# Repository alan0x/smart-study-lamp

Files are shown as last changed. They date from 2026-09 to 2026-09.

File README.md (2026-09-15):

# Smart Study Lamp / 学习台灯 V3

一套可用于 3D 打印打样的学习台灯结构模型。底座容纳 Mac mini M4，灯柱内可走线，并带有可拆屏幕支架和绿联 USB 摄像头安装模块。

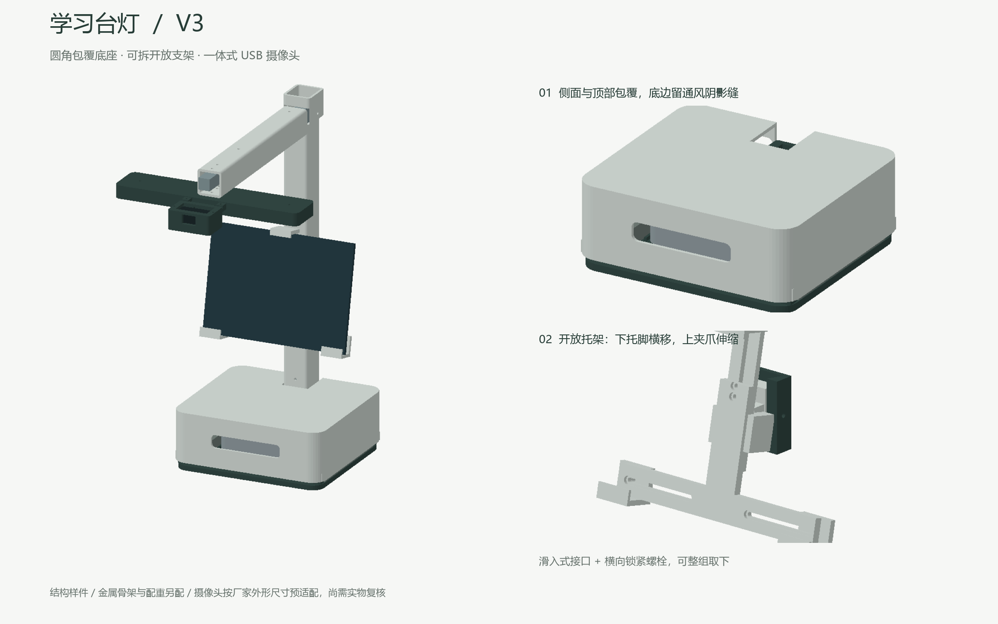
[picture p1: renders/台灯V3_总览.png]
V3 总览


## 当前设计

- 圆角包覆式底座，侧面和顶部遮蔽 Mac mini，底部保留进风空间。
- 20 × 20 × 1.5 mm 钢方管承重骨架；打印件只承担外壳、定位和连接作用。
- 可拆开放式屏幕支架，目标夹持高度 130–220 mm。
- 摄像头安装腔按不含底座的 59 × 35 × 23 mm 机身设计。
- 灯柱与横臂内预留线束通道，并给屏幕、LED 和摄像头设置出线口。
- 灯头预留通用 LED 铝槽容纳空间；灯条、铝槽、扩散罩、调光器和电源尚未选定。

## 查看模型

- `assembly_view_only.glb`：完整装配预览，包含设备和金属骨架占位，不可整体打印。
- `assembly_view_only.3mf`：同一装配的 3MF 版，可直接用 Bambu Studio 打开逐件查看，不可打印。
- `stl/`：18 个独立打印文件，单位均为毫米。
- `renders/`：整灯、爆炸图、分步装配与拆装渲染图。

Windows 可直接尝试打开 GLB；也可使用 Blender。查看和切片 STL 可以使用 [Bambu Studio](https://bambulab.cn/zh-cn/download/studio)。

## 打印前必读

这是结构样件，还未进行实物承重、防倾倒、温升、照度、眩光和摄像头覆盖范围测试。建议先打印 16–18 号配合试片，以及 09/10 号摄像头适配件。

完整尺寸、采购参考和装配顺序见：

- [设计与打印说明](docs/设计与打印说明.md)
- [V3 更新与走线说明](docs/V3更新与走线说明.md)

## 重新生成模型

建模源文件位于 `model/build_lamp_v3.py`。安装依赖后，在仓库根目录运行：

```powershell
python -m pip install -r requirements.txt
python model/build_lamp_v3.py
```

脚本会在 `outputs/V3` 下重新生成 STL、预览图和校验结果。中文标注渲染目前会优先使用 Windows 的微软雅黑字体。

整灯爆炸图由 `model/build_exploded_view.py` 生成，分步装配示意由 `model/build_assembly_steps.py` 生成（均会先完整运行建模脚本），分别输出到 `renders/台灯V3_爆炸图.png` 和 `renders/台灯V3_分步装配.png`。

## 版本状态

V3 已完成数字几何检查：18 个 STL 均为封闭、正体积、单一连通网格；打印件、设备包络和预留线束探针没有检测到体积干涉。数字检查不能替代实物装配和安全测试。

本仓库暂未声明开源许可证；未经许可，不自动授予复制、修改或再发布权利。

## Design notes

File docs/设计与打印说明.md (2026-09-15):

> V3 补充说明优先：摄像头依据客服提供的本体约 59×35×23 mm 建模。视场角未确认，当前高度并未证明能覆盖 600×400 mm 桌面。

# 学习台灯 V3：圆角外罩、开放式可拆支架、USB 摄像头成品适配

## 这次改动

1. Mac mini 与两侧配重收进圆角底座，侧面与顶面包覆，顶部不再有通风栅格或外露紧固件。底边留通风缝，前面留接口窗口，后面留插线窗口。
2. 屏幕改成开放 T 形托架：两只下托脚左右移动，上夹爪上下伸缩。支架通过滑入式连接座安装到灯柱，拔出横向锁紧螺栓、上提约 66 mm 后，可整组取下。灯柱连接座可以保留供以后安装别的模块。
3. 摄像头按 **UGREEN 59×35×23 mm** 金属外壳成品预适配，摄像头与 mic 共用 USB 线，原装金属外壳保留；不用把带显示器夹具的现有摄像头塞进小仓内。

这是经过数字几何检查的 **V3 结构样件**，可以询价、试打。承重、跌落、防倾倒、温升、照度和摄像头实拍尚未验证，不能视为已经定型的整灯。机身尺寸通过不代表按键、底脚、实际线缆和镜头细节已经全部确认。

## 文件内容

- STL 文件夹：**15 个装配件 + 3 个配合试片，共 18 个文件**，每个各 1 件。
- 台灯V3_总览.png：真实模型渲染，包含整灯和局部外观。
- 台灯V3_爆炸图.png：整灯爆炸图，标注打印件编号与另购件位置，由 model/build_exploded_view.py 生成。
- 台灯V3_分步装配.png：六步装配示意，含每步紧固件要点，由 model/build_assembly_steps.py 生成。
- 台灯V3_拆装细节.png：底座、屏幕连接、摄像头安装座的拆解示意。
- assembly_view_only.glb：保留装配坐标的三维查看模型，包含非打印设备与金属骨架占位，不能整体打印。
- mesh_validation.json：网格、干涉和若干运动位置检查结果。
- editable_model.py：可编辑建模源文件，需 Python、numpy、trimesh、manifold3d、matplotlib；运行目录中生成 outputs/V3。图片需系统可用中文字体。
- V3更新与走线说明.md：摄像头尺寸、走线路线与实物复核要求。

STL 单位均为 **mm，按 100% 比例导入**。每件独立摆放，不保留装配位置；部分件已旋转以便切片。不要通过整件缩放来调整局部配合。以 GLB 查看装配关系，以 STL 单件打印。

## 主要尺寸

| 项目 | V3 |
|---|---|
| 底座包络 | 260 × 240 × 98 mm，不计另贴的防滑脚垫 |
| 外壳 | 侧壁约 4 mm、顶板 4 mm、平面转角半径 24 mm |
| 底座通风 | 外罩下沿高 14 mm，内底板上表面高 8 mm，中间留 6 mm 通风阴影缝 |
| Mac 底面 / 顶面 | 名义 Z=30 / 80 mm，罩内顶面 Z=94 mm，顶上约 14 mm 空间 |
| 总高 | 584 mm，不计防滑脚垫 |
| 灯头主体 | 320 × 68 × 22 mm |
| 摄像头名义镜头位置 | 约 X=0、Y=-308、Z=491 mm，实际光心待实物确认 |
| 屏幕设计范围 | 目标设备 iPad Pro 11″（2021，247.6×178.5×5.9 mm，466 g）横放；夹持高度 130–220 mm；结构试配宽度约 140–250 mm；厚度约 6–13 mm 需软垫补偿 |
| 屏幕姿态 | 后倾 12°，V3 没有角度转轴 |
| 下托脚中心 | 左右各可在距中线 35–106 mm 的位置锁紧；iPad Pro 11 横放建议各 106 mm，使底边完全承托 |

这里的“夹持高度”指上下接触边之间的距离，不是屏幕对角线。按设备实际长宽和摆放方向判断是否适用，例如较大的平板可能需要横放。宽度只是结构适配目标，没有经过所有设备试装。台灯整体承载上限尚未通过测试；首轮应从与 iPad Pro 11（466 g）等重量的假负载开始验证，不能据此装大尺寸桌面显示器。

托架没有四边包框，两侧接口通常更易露出，但上夹爪、下托脚仍可能遇到特定机型的按键、USB 接口或磁吸附件。软垫应补偿厚度与保护接触边，不要硬夹显示区域。后部螺栓头采用凹位，必须选择能藏入凹位的低圆头螺栓，避免顶到设备背面。

## 底座：包起来，但保留真实风路

Mac mini M4 的通风经过底脚区域，Apple 官方介绍了这一结构。[Apple 的 M4 Mac mini 发布说明](https://www.apple.com.cn/newsroom/2024/10/apples-all-new-mac-mini-is-even-more-mighty-and-more-mini/)

因此外罩覆盖侧面与上面，电脑下方只保留四个短托点，中央开放；配重位于电脑左右，不放在电脑底部。外罩下沿不贴住内底板，空气从底边和后侧窗口进出。Mac 前后接口用较大的共用窗口让位，未按未经核实的端口坐标逐孔开小孔。

6 mm 通风缝、30 mm 底面高度和14 mm 顶部间隙均是初始设计值，不是热设计结论。包覆后仍需与裸机对比满负载温度、风扇噪声和性能；若出现热积聚，应扩大下缘或后部通风区域。外壳不能贴合封死底脚。底面电源键的手指操作与真实底脚需试装，必要时拆罩操作。

外罩用底面四颗 M3 螺丝固定，顶部无外露螺丝；螺纹由四个 M3 热熔嵌件提供。外罩后面有 U 形灯柱让位缺口，拆外罩不必拆整根灯柱。建议先取下屏幕模块，拔掉电脑外接线，再卸底面螺丝，提罩约 80 mm 后向前移出。拆解图为了显示内部使用了更大的抬升距离，不代表唯一拆卸路径。

## 分件清单

| 编号 | 部件 | 数量 |
|---|---|---:|
| 01 | 隐藏式内底架、电脑托点和方管插座 | 1 |
| 02 | 圆角外罩 | 1 |
| 03 / 04 | 灯柱下 / 上套壳 | 各 1 |
| 05 / 06 | 灯臂后 / 前套壳 | 各 1 |
| 07 | 转角罩 | 1 |
| 08 | 圆角灯头 | 1 |
| 09 / 10 | 绿联成品摄像头承座 / 后压盖 | 各 1 |
| 11 | 固定在灯柱上的滑入连接座 | 1 |
| 12 | 开放屏幕载架，后方一体式插舌 | 1 |
| 13 / 14 | 左 / 右下托脚 | 各 1 |
| 15 | 可滑动上夹爪 | 1 |
| 16 | 20.6 mm 方管孔试片 | 1 |
| 17 / 18 | 滑轨母槽 / 公舌配合试片 | 各 1 |

## 金属、紧固件与电子件

### 承重骨架与配重

初始骨架用 20 × 20 × 1.5 mm 钢方管：立管长 532 mm，横管长 384 mm，由加工方焊成刚性倒 L 形。打印外壳不替代金属承重。立管全长穿过底座、两段灯柱，横管穿过两段灯臂。

坐标：底座中心 X/Y=0；Y 负向朝使用者；Z=0 为底板底面。立管范围 X ±10、Y=89…109、Z=8…540；横管范围 X ±10、Y=-275…109、Z=540…560。加工方要验证焊接质量、清理焊瘤、管端去毛刺，并保护线缆。

两块 30 × 180 × 20 mm 钢配重，中心分别 X=±110、Y=0、Z=18，合计约 1.7 kg。每块两孔，沿长方向中心距 140 mm，对应底架 X=±110、Y=±70 的 Ø5.4 孔，以 M5 螺栓固定。配重全部在外罩内。贴防滑脚垫，首次装配用假负载进行四方向稳定性测试，触屏推力和拉线也要考虑；配重数值不等于已验证的防倾倒保证。

### 紧固件参考表

| 位置 | 孔位 / 要求 | 初始采购参考 |
|---|---|---|
| 底座—立管 | X=0，Z=28/62，沿 Y，Ø4.4 | M4×50，2 套 |
| 下灯柱—立管 | X=0，Z=110，沿 Y | M4×60，1 套 |
| 滑入连接座—灯柱—立管 | X=0，Z=278/292，沿 Y | 低圆头 M4×65，2 套 |
| 上灯柱—立管 | X=0，Z=345/510，沿 Y | M4×60，2 套 |
| 后灯臂—横管 | X=0，Y=45，沿 Z | M4×55，1 套 |
| 前灯臂—横管 | X=0，Y=-145，沿 Z | M4×55，1 套 |
| 灯头—横管 | X=0，Y=-245/-225，沿 Z | M4×60，2 套 |
| 转角罩—横管 | Y=99，Z=550，沿 X | M4×60，1 套 |
| 屏幕接口防脱锁紧 | Y=55，Z=285，沿 X，穿母槽和公舌 | M4×70 手拧螺栓 + 蝶形螺母，1 套 |
| 两只下托脚、上夹爪 | 2 颗下托脚 + 2 颗上夹爪，沿托架局部 Y | 低圆头 M4×25，4 套；后方手拧螺母 |
| 圆角外罩—内底架 | X=±118、Y=±100；从底面装 | M3×16，4 颗；M3 热熔嵌件 4 个，预留外径 5.2、深 6 mm 孔 |
| 配重—底架 | X=±110、Y=±70 | M5×35，4 套，底面头部凹位 Ø9 × 4 mm |
| 摄像头承座—灯头 | X=±30、Y=-276 | M3×16，2 套 |
| 摄像头后压盖—承座 | X=±34、Y=-313 | M3×40，2 套 |
| LED 铝槽—灯头 | X=±130、Y=-235 | M3 两套，长度按实际铝槽确认 |

长度需根据垫片、螺母和实际零件复核。M4 穿管处用防压套、平垫与防松螺母；不可过度拧紧压坏管壁和打印件。屏幕前侧螺栓头直径必须小于 Ø8.2 mm、头高不超过 3 mm，连接座凹位深 4 mm。不要用普通高圆柱头直接替换低圆头。外罩嵌件孔要按实际品牌规格与材料试装，不能仅靠标称“M3”推定外径通用。

滑入接口有底部止挡，横向螺栓防止上提脱出。**必须装好横向锁紧螺栓后使用**，不要只靠重力悬挂。取下屏幕模块前托住重量，拔掉连接屏幕的线，卸锁紧螺栓，再上提约 66 mm 移出。它不是无需解锁就能提起的卡扣。

### 摄像头与灯光

09/10 号件内部预留约 62 × 38 mm 空间，按绿联本体 59 × 35 × 23 mm 预适配。镜头朝下，前脸四处小托唇限位，背面用压盖加软垫固定。镜头面大部分开放，不能用玻璃或透明打印片封住。

厂家未给出完整机械图，因此前脸托唇是否挡住声孔、实际镜头凸出、USB 出线和压盖接触区域，必须收到实物后确认。不吻合时只重做 09/10 号适配件。麦克风声孔和镜头不能被垫片、胶带或打印件挡住；不要为了适配拆开成品摄像头。

光源仍采用外购低压 LED 模组、铝散热槽与扩散罩。内部示意槽尺寸 296 × 18 × 8 mm，灯头内腔约 312 × 60 mm；实际模块功率、固定孔、扩散罩和温升需进一步选型验证。电源外置，LED 不直接贴塑料。灯头机械形状不能保证桌面照度、无频闪或无眩光。

## 走线

实际通道、出口、短段外露线及装配顺序，以同包《V3更新与走线说明》为准。线缆走在金属骨架与打印套壳之间，先穿线后组装；不可理解为装好后能直接穿过任意USB插头。

## 打印与装配

1. **先试片**：16 号验证方管配合，17/18 号验证滑轨间隙。再打 11–15 号支架试装设备。摄像头到货后再确认 09/10 号，不建议一次性打印全部。
2. 材料从 PETG / ASA 评估，初始可按 0.2 mm 层高、5–6 道外壁安排；承力处局部实心，具体填充、方向和支撑由商家结合材料确认。热源附近要有温升测试。
3. 外罩顶面已朝下输出，内部小安装凸台可能需要支撑；支撑必须能清理。灯头顶面也朝下；屏幕件已消除 12° 装配倾角，但复杂后接头仍需要重新评估摆放和局部支撑。没有实际切片报告。
4. 最大件宽 320 mm；不受家用打印机尺寸约束，商家须选合适机型。V3 与 V1 的局部形状已改变，不要混用两个版本的 STL。
5. 金属骨架完成后预穿线、套入各段外壳、固定到底架。安装配重，连接座和灯臂；放好 Mac，再装圆角外罩。
6. 先把夹爪调到略大于设备的尺寸，放软垫、装设备，轻压上夹爪后锁紧；两只下托脚应对称且完全承托边缘。再将整个模块滑入母座并装锁紧螺栓。
7. 安装 LED 铝槽、扩散罩及摄像头组件。检查插头、按钮、风道和电源键可达性。
8. 用实际 USB 视频 / 音频软件确认识别、帧率和拾音，再验证目标桌面范围、文字清晰度、受力与温升。

## 数字验证范围

- 18 个 STL 均为单一连通封闭实体、法向一致、正体积。
- 15 个打印装配件的两两实体交叠检查通过。
- 对 Mac、iPad Pro 11（2021）、绿联壳体及配重包络做了无干涉检查。包络不是厂家详细 CAD，未包含真实按钮、镜头细节、脚垫、螺丝、线缆等。
- 检查上夹爪高度 130 / 150 / 175 / 200 / 220 mm 的位置，以及载架上提 0 / 10 / 30 / 50 / 66 mm 的位置，没有发现对应接口干涉；属于离散位置检查，不是结构寿命试验。

设备外形基础：[Mac mini M4 官方规格](https://support.apple.com/en-ie/121555)、[iPad Pro 11″（第三代）官方规格](https://support.apple.com/en-us/111897)。摄像头适配要求见同包《V3更新与走线说明》。

## 照明完成度补充

当前08号灯头只有通用容纳空间和两个安装孔，没有针对已选购灯条设计卡扣；296×18×8 mm铝槽是示意占位，不能作为已适配某款商品的承诺。没有控制板螺柱、按钮孔、电源插座安装座，也没有独立打印扩散罩或扩散罩固定槽。推荐初步采用成品低压灯条、匹配铝槽及乳白扩散罩、外置带壳调光器与电源；灯条长度需满足实际裁切节距。选定照明部件后需复核孔位、接线和温升，再定稿灯头。

## 照明选型参考

以下为验证期选型建议，属于采购参考，几何尚未按具体商品定稿。读写台灯照度目标参考国 AA 级：桌面中心约 500 lx 以上，可用手机照度计 App 粗测。

- **灯条**：COB 低压灯条（连续发光面，优于 SMD 灯珠条的颗粒感），12V、4000K 色温、显色指数 Ra≥90、10–15 W/m。4000K 是夜间读写的常见建议上限。裁 296 mm 一段装入示意槽，功率约 3–4.5 W；灯头内腔宽 60 mm，照度不足时可并排加装第二条 18 mm 铝槽。灯条只能按裁切节距剪断（12V COB 常见为每 25 或 50 mm 一个剪点）。
- **铝槽与扩散罩**：17–20 mm 宽 U 形成品铝槽套件，自带乳白 PC 扩散罩、端盖和卡扣，按 296 mm 截断。铝槽承担散热，是"LED 不直接贴塑料"的实现方式；V3 灯头预留的 M3 孔（X=±130）用于固定单槽，加装第二条槽时复核并补充孔位。
- **电源与驱动**：12V 恒压灯条不需要驱动板，限流已做在灯条上，外置 12V 适配器即驱动。暂无调光需求，选自带动线开关的灯条套件或在 DC 线上串接线上开关。
- **点亮后验证**：照度（中心 500 lx 以上，不足加第二条槽或换高功率灯条）；频闪（手机摄像头对灯观察有无滚动条纹，有则更换适配器）；温升（铝槽表面及铝槽与打印件接触处，PETG 软化点约 80 °C，10 W 级灯条铝槽表面预计 40–60 °C，需实测）。

参考量级：COB 灯条 1 m 约 ¥20–40，铝槽套件 1 m 约 ¥15–30。

## 供电规划（备选方向记录）

**当前决策：保留 Mac mini + iPad Sidecar + 独立 USB 摄像头架构，V3 几何不变，V3.1 薄底座方案搁置。** Mac mini 使用自身电源（市电经底座后窗进入）；iPad 经屏幕支线（Z=240 出口）充电；摄像头由 Mac 的 USB 口直供。整灯只需为 LED 单独配一只外置 12V 适配器，规格见《照明选型参考》。

以下为"去 Mac mini"备选方向的供电规划记录，暂不实施。原规划原则是**市电不进灯**：3D 打印外壳内只走低压直流，外置一只 12V / 5A（60W）适配器作为整灯总电源。内部按 12V 母线分配：

| 负载 | 电压 | 功率量级 | 供电方式 |
|---|---|---|---|
| LED 灯条 | 12V | 8–15 W | 12V 直供，灯条套件自带开关 |
| WiFi 摄像头模组 | 5V | 约 3 W | 12V→5V buck 模块 |
| 平板充电 | USB PD | 18–30 W | 12V→PD 诱骗/车充模块 |
| （可选）安卓主板 | 5V | 约 10 W | 另一路 buck 模块 |

buck 与 PD 模块均为成品小板，计划在 01 底架上加 M2/M3 安装柱，底座后部开 DC 插座（5.5×2.1）面板孔；走线通道尺寸不变，线束内容由 USB 数据线改为 LED 2 芯、摄像头 5V 2 芯、屏幕充电 2 芯，装配说明随 V3.1 同步更新。以上接口与安装位待 V3.1 改模时落进几何，落模前不要按本节开孔。

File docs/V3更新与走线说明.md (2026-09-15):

# V3 更新与走线说明

## 更新件
01 底架、03 下灯柱、04 上灯柱、06 前横臂、09 摄像头承座、10 后压盖。其余零件沿用 V2 几何；本包提供完整 18 件 STL，单位 mm。

## 摄像头
按客服提供的不含底座本体 59×35×23 mm，旋转为镜头向下。承座内腔 62×38 mm，外轮廓约 74×50 mm，主体深29 mm。后压盖开口54×30 mm，使用软垫补偿侧向约1.5 mm间隙及后方间隙；不靠拧紧压盖挤压机身。前面四个短边托唇保留，其是否避开实际麦克风孔需要实物确认。上下边留控制开口，但准确按钮、镜头和USB接口位置尚未提供，几何检查只使用本体包络和假设位于背面中央的14×12×28 mm插头空间。不是按准确接口图完成的紧配合产品。

## 走线
旧版已有空心套壳，但入口和转接处不完整。V3补齐以下开口：
- 底座立柱插座前方：26×18 mm槽，向上与灯柱空腔衔接。
- 灯柱顶端前壁：26×12 mm转角穿线窗口。
- 横臂底面：14×12 mm窗口，与LED灯头原有14×12 mm窗口对齐。
- 下灯柱前壁：16×12 mm屏幕支线出口，中心距底板240 mm。

路线：底座后窗→底座内部→金属立柱前侧→顶部转角→金属横臂下方→横臂前端→摄像头。LED在横臂底部窗口分支；屏幕在下柱前壁分支。

灯柱套壳内部34×40 mm，但金属立柱占20×20 mm；前侧主要净深约19 mm。横臂套壳内部34×36 mm，金属横管下方净高约13 mm。不可将整个空腔当作线束容量。

主线束靠左偏置（中心X=-9 mm），避开中心贯穿螺栓；数字检查使用6×8 mm连续直段线束包络，转角保留松弛弯曲余量。实际弯曲半径、多线束、扎带、螺母及焊接接头需要装配确认。不要把线束拉直贴住螺栓。装配时先穿线，再套合打印件及装入紧固件；不能保证大USB-A插头在整灯装好后可以从头穿到底。

摄像头背面至横臂前端、屏幕出口至iPad仍有短段外露软线：使用软护套整理，并给可拆屏幕保留服务环。本版没有为这两段另做封闭线罩。走线空间与插头空间不同，成品USB线应先试穿，按实际接口位置确认接头长度。

## 检查结果
18个STL均封闭、正体积且单一连通；打印件之间、设备本体包络之间无体积干涉。6组走线/插头空间探针与打印件及金属骨架无体积干涉。该检查不等于整束实线、弯曲半径或USB插头穿入运动验证。

建议先试打09、10，带摄像头和实际线缆试装后再批量打印。当前镜头高度仍约491 mm；600×400 mm桌面覆盖范围待视场角或实拍确认，未因本次机身尺寸更新改变灯高。

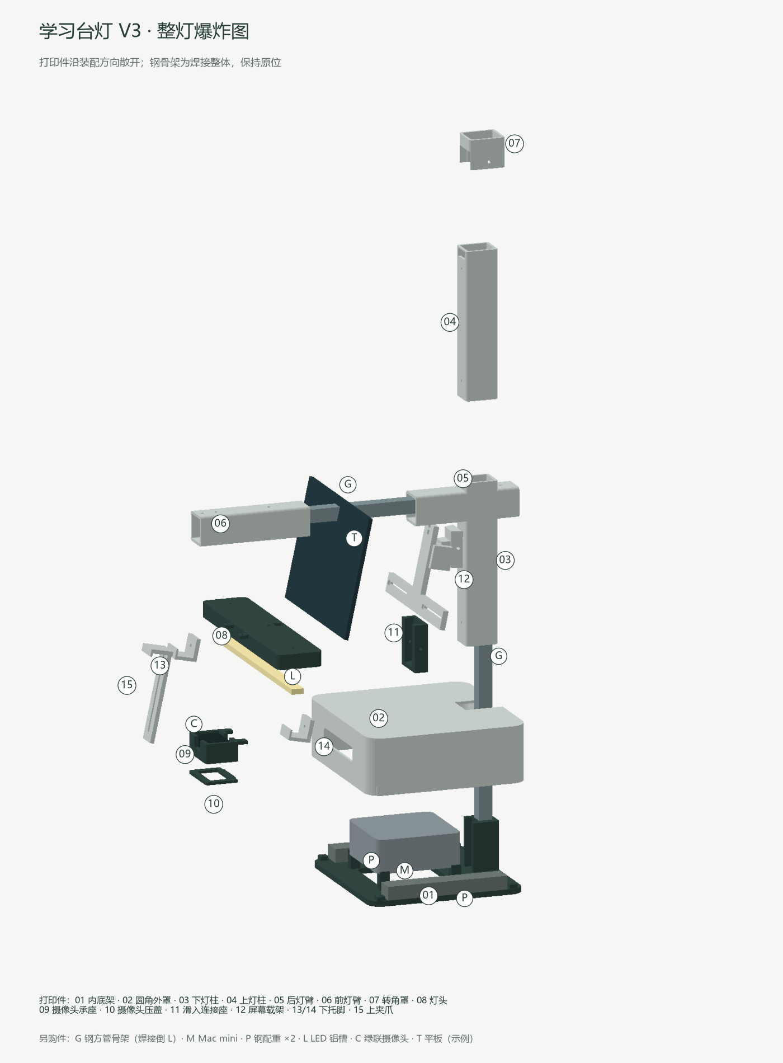
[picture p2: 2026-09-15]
renders/台灯V3_爆炸图.png

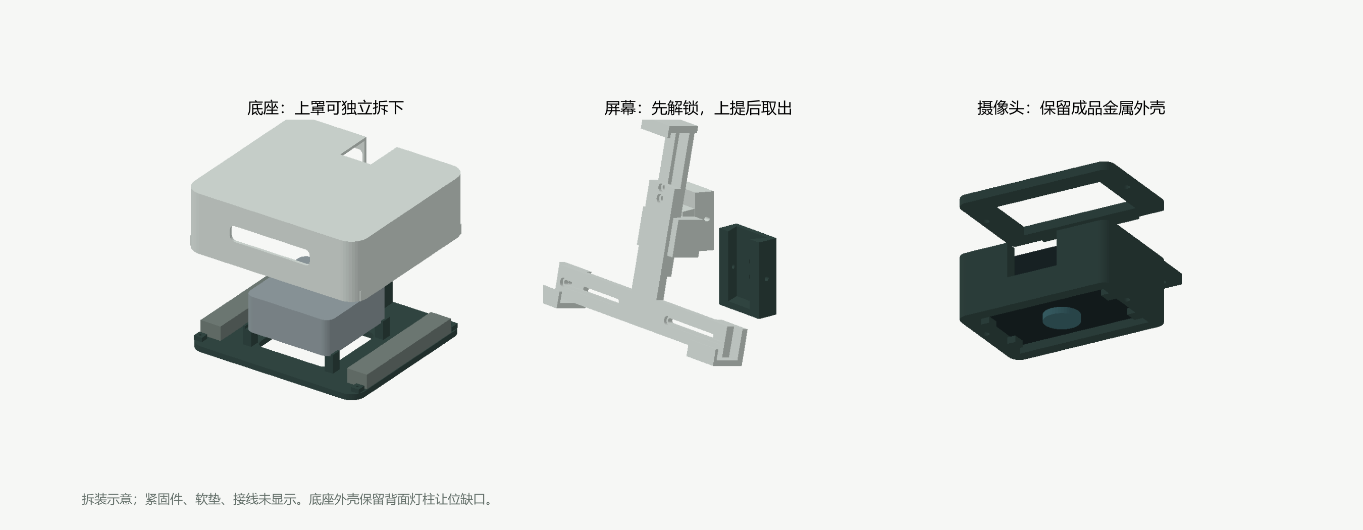
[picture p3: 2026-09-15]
renders/台灯V3_拆装细节.png

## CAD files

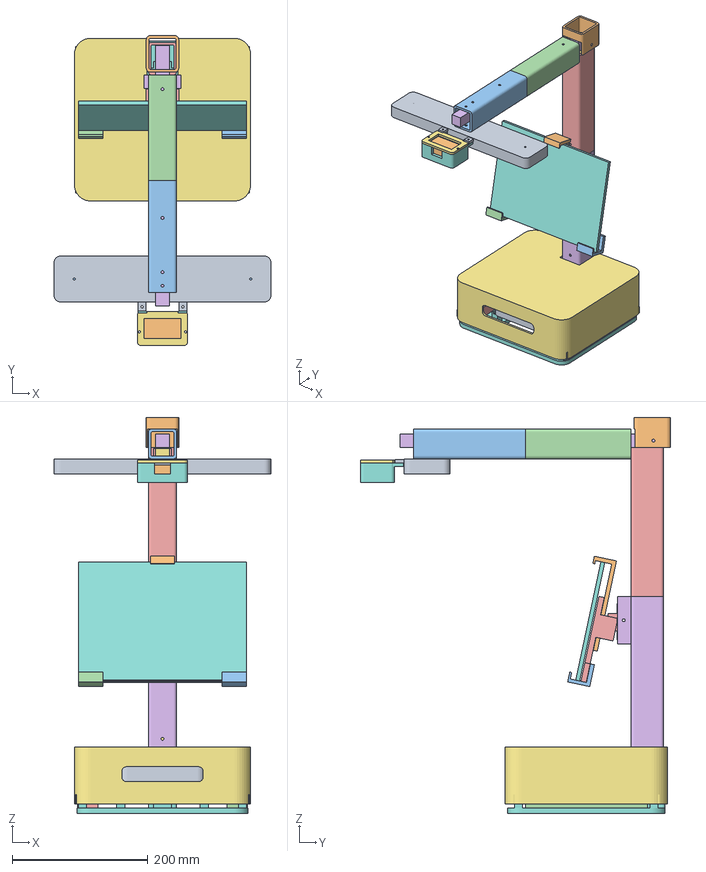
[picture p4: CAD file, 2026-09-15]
assembly_view_only.3mf
320.0 x 457.0 x 584.0 mm
lens_illustrative
UGREEN_case_envelope
LED_aluminum_envelope
ballast_110
ballast_-110
steel_arm
steel_spine
iPad_Pro_11_envelope
Mac_mini_envelope
15_screen_sliding_upper_jaw
14_screen_lower_foot_right
13_screen_lower_foot_left
12_open_screen_carrier
11_column_slide_dock
10_camera_rear_keeper
09_UGREEN_59x35x23_cradle
08_rounded_LED_head
07_corner_cover
06_arm_front_165
05_arm_rear_156
04_column_upper_220
03_column_lower_240
02_rounded_mac_shell
01_hidden_chassis

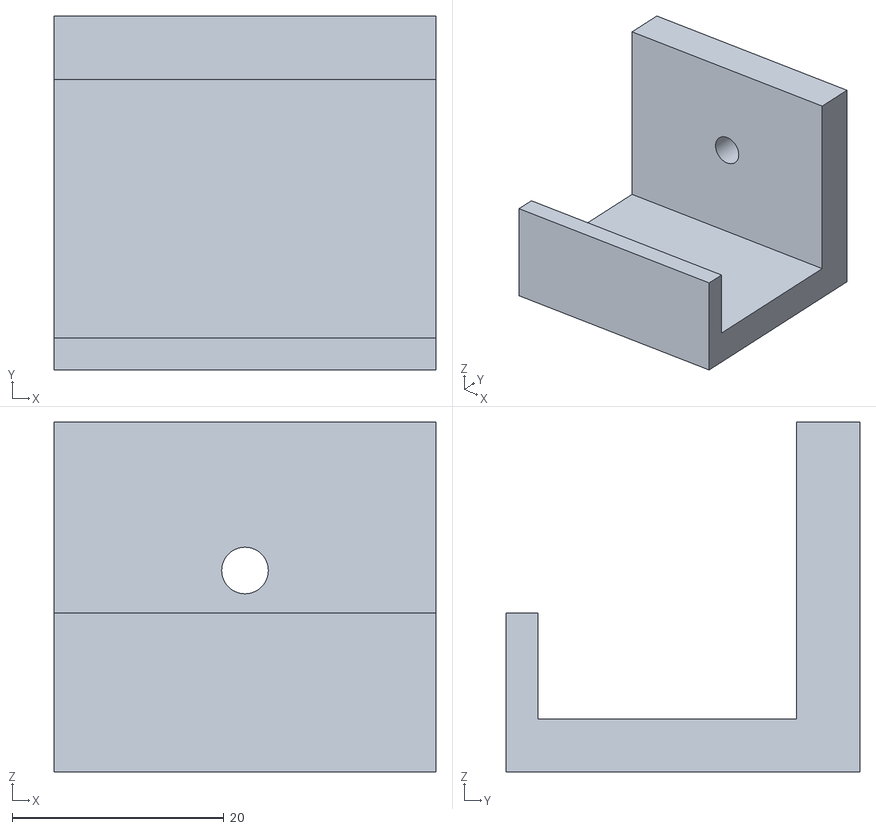
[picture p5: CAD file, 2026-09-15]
stl/13_screen_lower_foot_left.stl
36.0 x 33.4 x 33.0

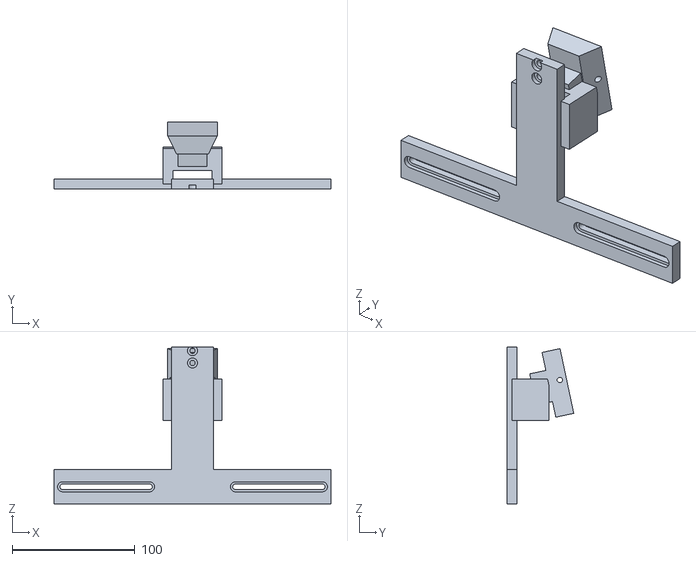
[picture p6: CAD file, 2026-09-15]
stl/12_open_screen_carrier.stl
226.0 x 54.3 x 128.0

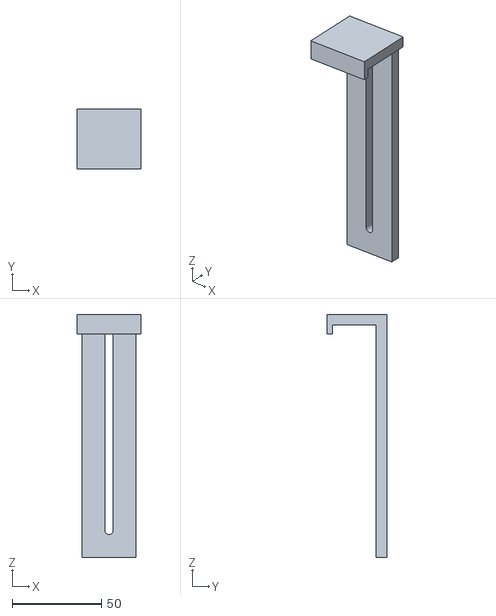
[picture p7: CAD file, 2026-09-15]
stl/15_screen_sliding_upper_jaw.stl
36.0 x 33.4 x 136.0

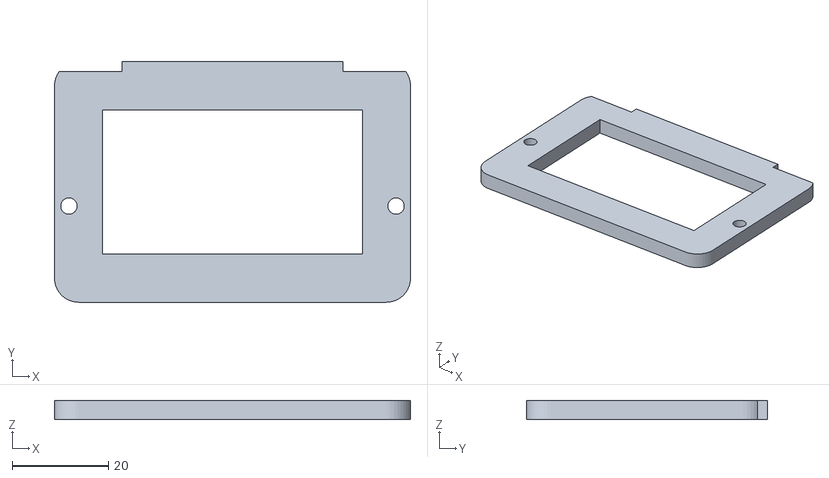
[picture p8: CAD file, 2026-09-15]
stl/10_camera_rear_keeper.stl
74.0 x 50.0 x 4.00

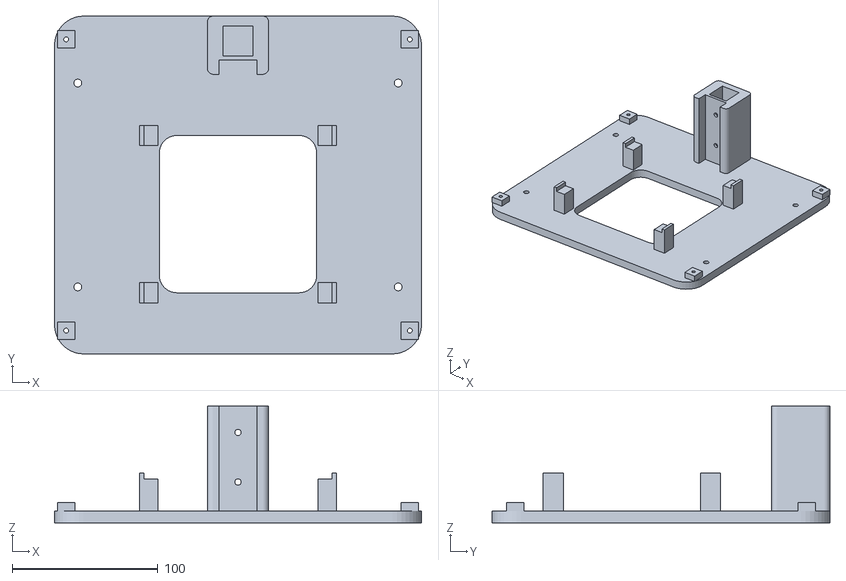
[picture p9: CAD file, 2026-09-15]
stl/01_hidden_chassis.stl
252.0 x 232.0 x 80.0

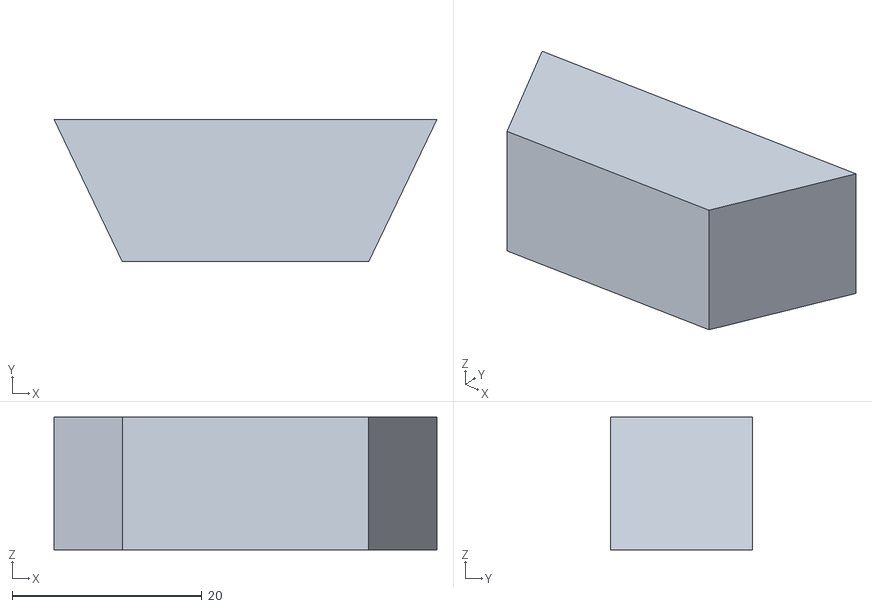
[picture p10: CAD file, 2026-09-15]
stl/18_slide_male_fit_coupon.stl
40.4 x 15.0 x 14.0

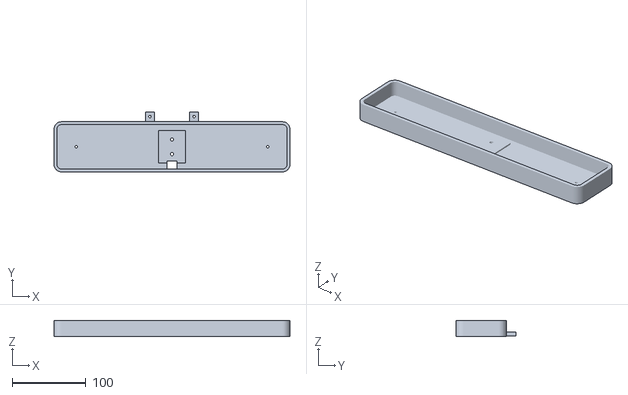
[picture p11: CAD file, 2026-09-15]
stl/08_rounded_LED_head.stl
320.0 x 81.0 x 22.0

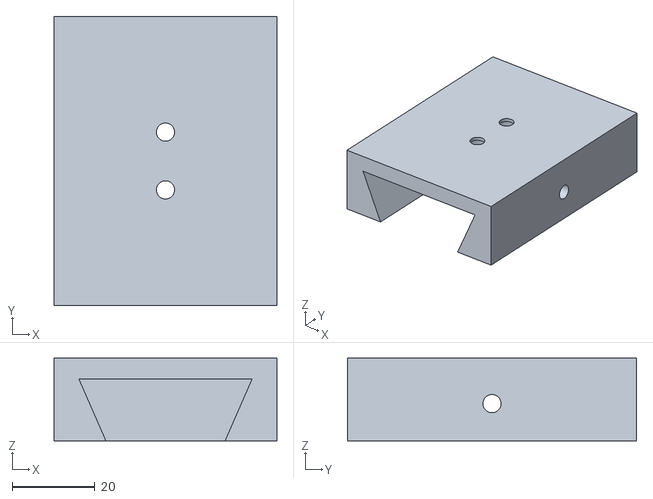
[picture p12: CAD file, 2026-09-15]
stl/11_column_slide_dock.stl
54.0 x 70.0 x 20.0

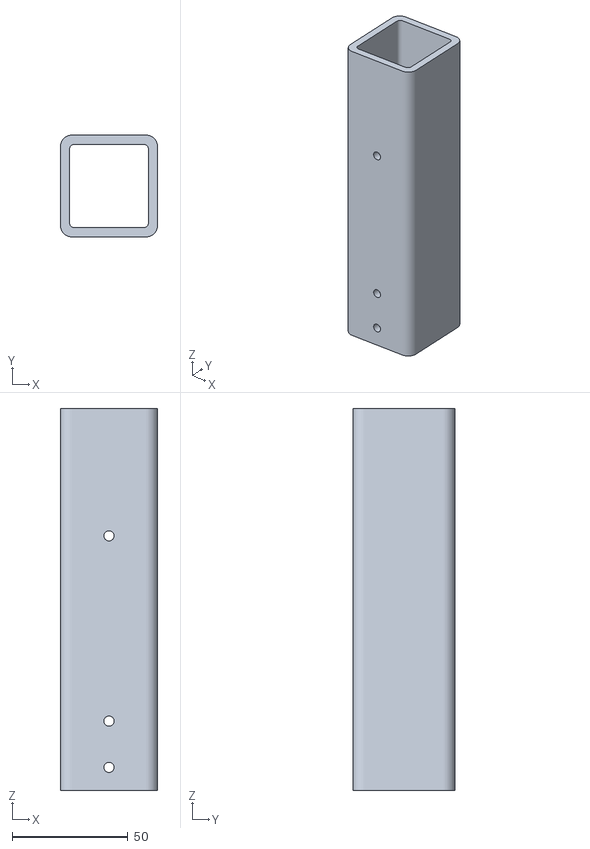
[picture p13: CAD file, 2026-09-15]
stl/06_arm_front_165.stl
42.0 x 44.0 x 165.0

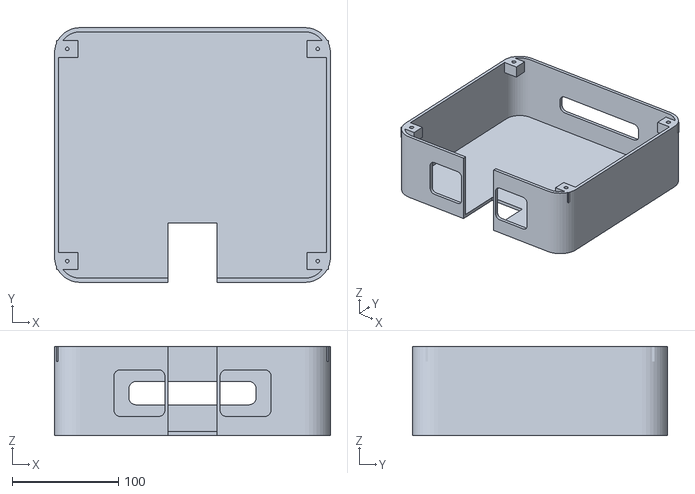
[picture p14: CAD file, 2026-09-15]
stl/02_rounded_mac_shell.stl
260.0 x 240.0 x 84.0

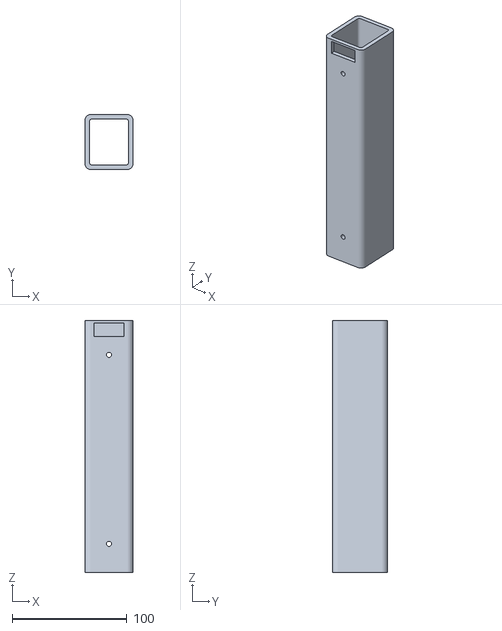
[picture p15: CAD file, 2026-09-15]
stl/04_column_upper_220.stl
42.0 x 48.0 x 220.0

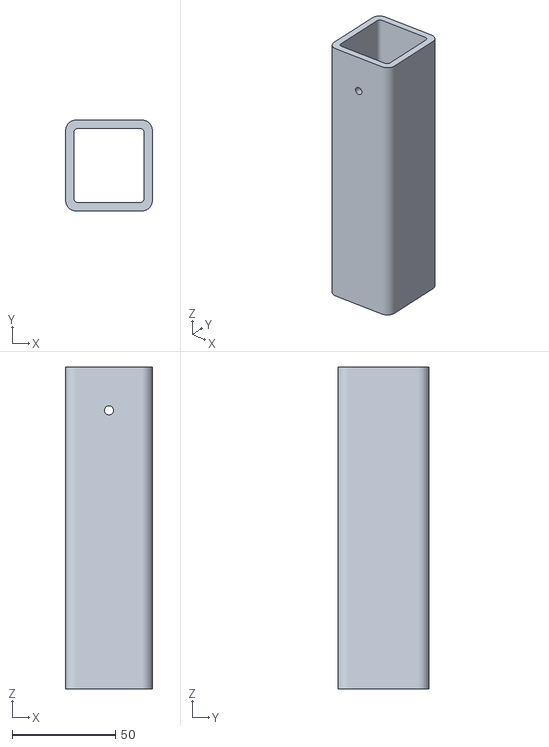
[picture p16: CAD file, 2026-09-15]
stl/05_arm_rear_156.stl
42.0 x 44.0 x 156.0

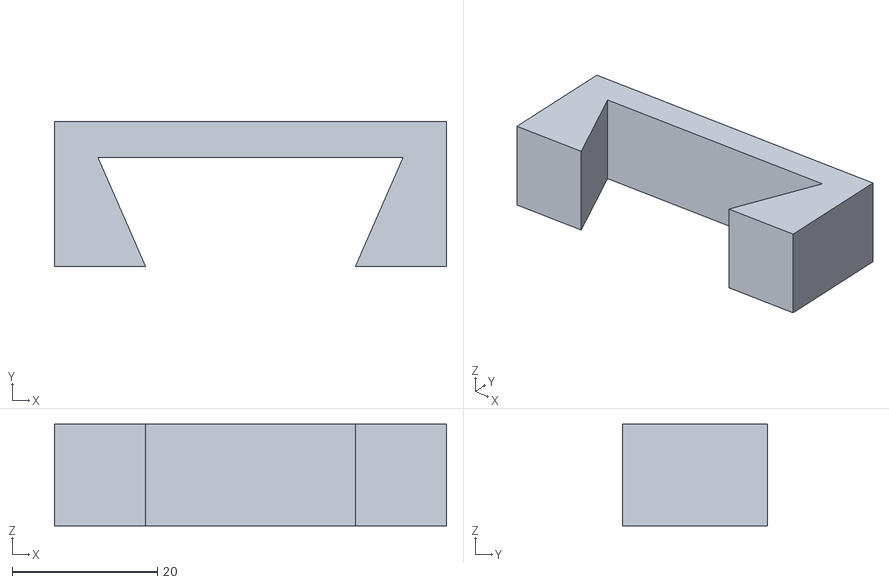
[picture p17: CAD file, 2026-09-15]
stl/17_slide_fit_coupon.stl
54.0 x 20.0 x 14.0

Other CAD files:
stl/07_corner_cover.stl
stl/03_column_lower_240.stl
stl/16_tube_fit_coupon.stl
stl/09_UGREEN_59x35x23_cradle.stl

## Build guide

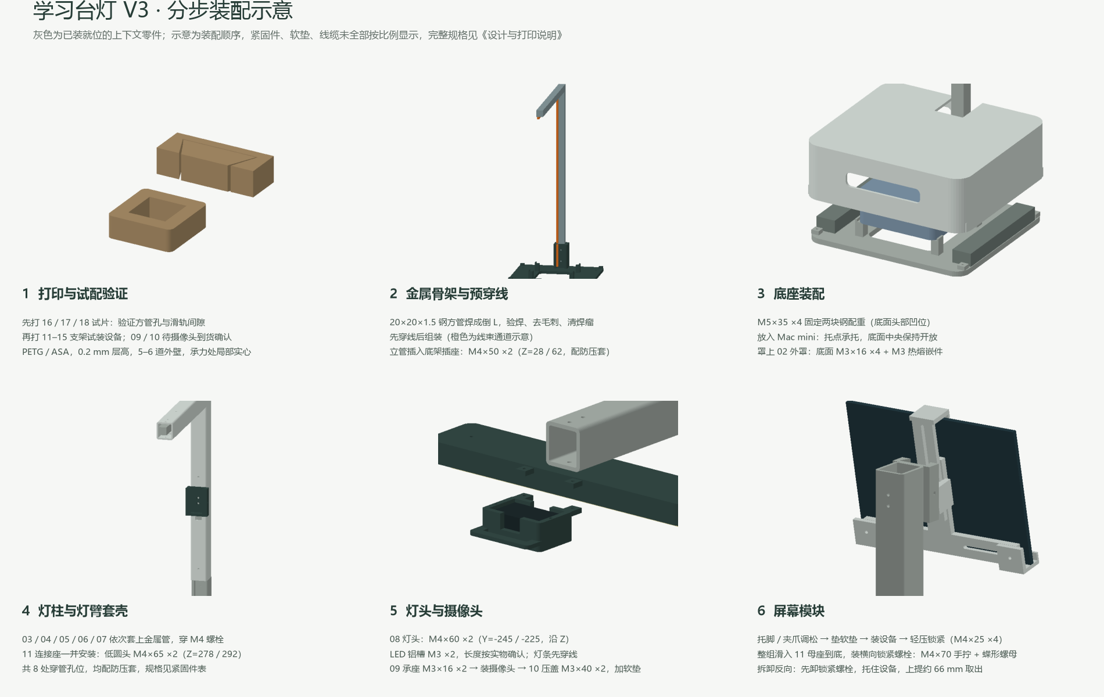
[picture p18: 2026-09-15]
renders/台灯V3_分步装配.png

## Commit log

2026-09-15 Initial V3 smart study lamp model
    [01_hidden_chassis.stl, 02_rounded_mac_shell.stl, 03_column_lower_240.stl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]
2026-09-15 Add assembly 3MF preview, exploded view and step-by-step assembly renders
    - assembly_view_only.3mf: named per-part assembly preview for Bambu Studio
    - model/build_exploded_view.py + renders/台灯V3_爆炸图.png: full exploded view with part badges
    - model/build_assembly_steps.py + renders/台灯V3_分步装配.png: 6-step assembly guide with fastener notes
    - docs: add lighting selection reference and V3.1 power supply planning sections
    [assembly_view_only.3mf]
2026-09-15 Adapt screen carrier for iPad Pro 11 (2021): widen crossbeam to 226mm
    - 12 carrier: crossbeam 180->226mm, foot slots extended to +/-106mm so feet fully support the 247.6mm bottom edge
    - 13/14 feet: default position +/-106mm; 15 jaw: default clamp height 178.5mm
    - Validation envelope switched from iPad mini to iPad Pro 11 (247.6x178.5x5.9mm)
    - Refresh STL/GLB/3MF/validation JSON and all renders
    - Add model/export_3mf_preview.py for repeatable 3MF preview export
    - Docs: update clamp range, foot travel, dummy-load weight, device spec link
    [12_open_screen_carrier.stl, 13_screen_lower_foot_left.stl, 14_screen_lower_foot_right.stl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]
